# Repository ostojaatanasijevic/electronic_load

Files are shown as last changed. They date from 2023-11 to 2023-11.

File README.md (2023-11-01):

# electronic_load
Open hardware modular electronic load

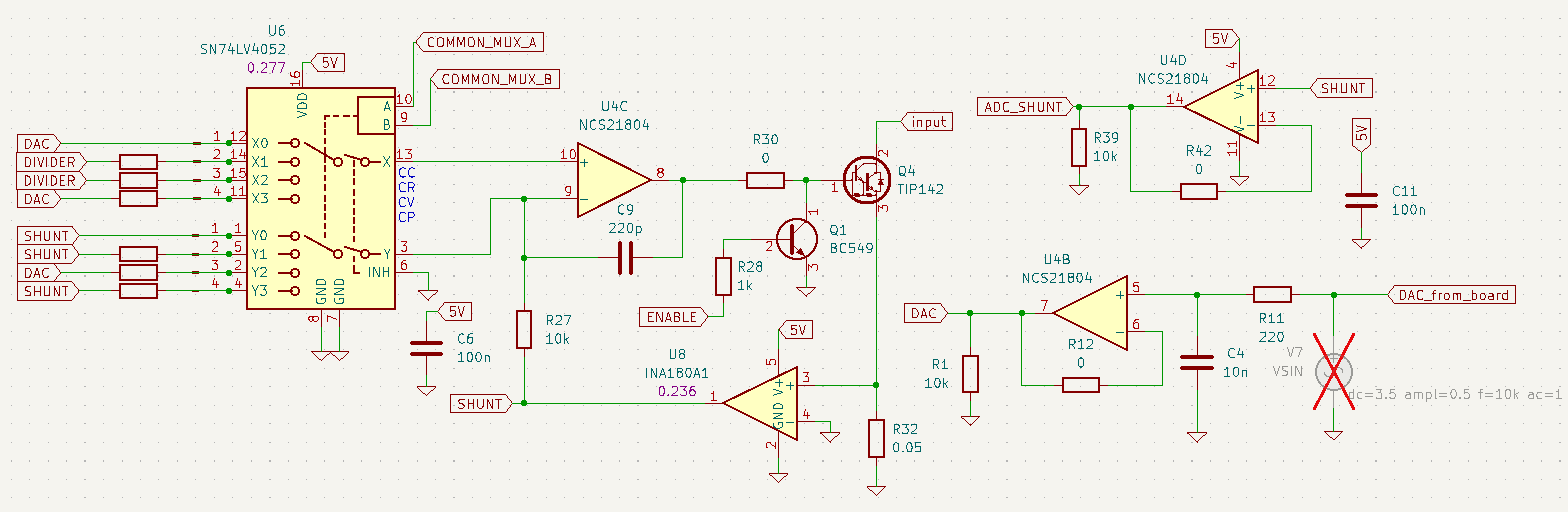
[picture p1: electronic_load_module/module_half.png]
Modular nature of the instrument is based around dual darlington module boards, each containing 2 of the schematic blocks shown below 
This module is designed for 8A and 2V - 60V operation with a maximum disipation of around 100W.

Control signals are generated by the general purpose front panel module. Using a panel with 12 bit ADC and DAC yealds 1 mA control
and sense accuracy.

Vcesat shortcoming of the darlington modules can be overcome by an addition of a singular mosfet based module. 

Additinal modules like the analog mixer circuit for fast CR and CP modes are in the works.

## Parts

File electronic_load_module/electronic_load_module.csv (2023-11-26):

Source: | /home/ostoja/Elektronika/Projekti/electronic_load/electronic_load_module/electronic_load_module.kicad_sch
Date: | Sun Nov 26 00:37:47 2023
Tool: | Eeschema 7.0.9
Generator: | /usr/share/kicad/plugins/extract_price.py
Component Count: | 43
Collated Components:
Item | Qty | Reference(s) | Value | LibPart | Footprint | Datasheet | DNP | Price | Sim.Device | Sim.Enable | Sim.Library | Sim.Name | Sim.Params | Sim.Pins | Sim.Type
1 | 2
2 | 5
3 | 2
4 | 2 | 0.184
5 | 2
6 | 2 | 0.04
7 | 2 | 0.02
8 | 2 | 0.994
9 | 2 | 2.52
10 | 6
11 | 2
12 | 2
13 | 2
14 | 2
15 | 2 | 0.704
16 | 1 | 1.91
17 | 1 | 0.412
18 | 2 | 0.554
19 | 2 | 0.472

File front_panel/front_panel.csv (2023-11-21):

Source: | /home/ostoja/Elektronika/Projekti/elektronsko_opterecenje/front_panel/front_panel.kicad_sch
Date: | Tue Nov 21 00:17:31 2023
Tool: | Eeschema 7.0.8
Generator: | /usr/share/kicad/plugins/extract_price.py
Component Count: | 39
Collated Components:
Item | Qty | Reference(s) | Value | LibPart | Footprint | Datasheet | DNP | Price | Sim.Device | Sim.Library | Sim.Name | Sim.Pins | Type
1 | 2
2 | 1 | 0.015
3 | 2 | 0.02
4 | 1 | 4.0
5 | 14 | 0.14
6 | 1 | 0.02
7 | 2 | 0.38
8 | 2
9 | 2
10 | 1 | 0.35
11 | 2 | 3.82
12 | 1 | 0.358
13 | 2 | 1.6
14 | 1
15 | 1
16 | 1 | 4.0
17 | 2 | 0.818
18 | 1 | 1.11

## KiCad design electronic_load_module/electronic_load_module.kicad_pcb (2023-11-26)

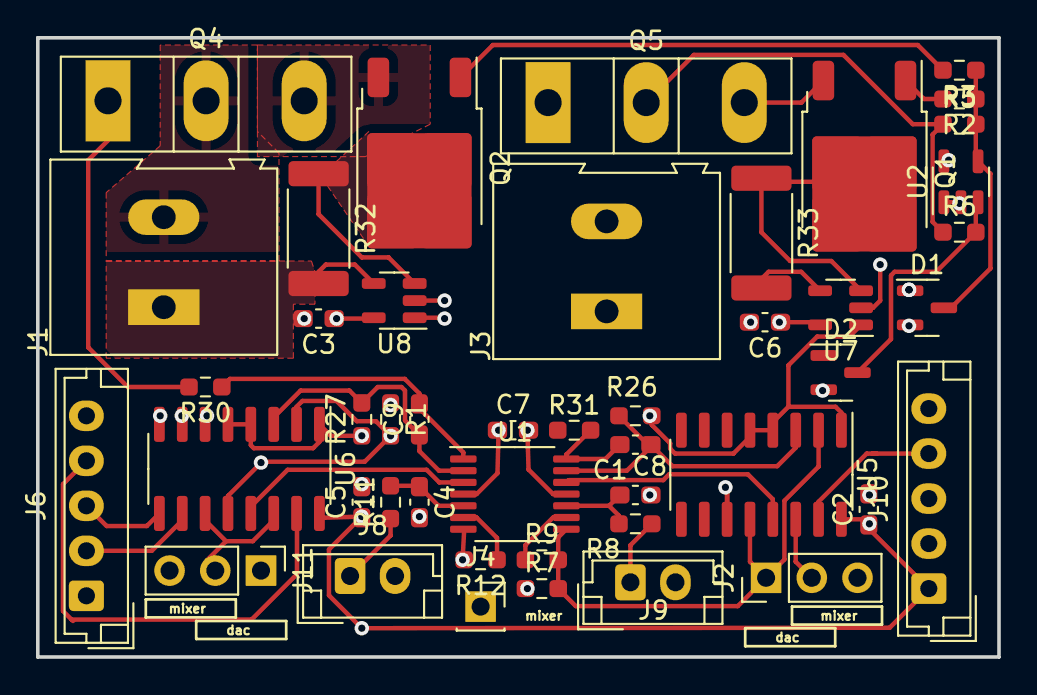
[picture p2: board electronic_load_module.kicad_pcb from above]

Board: 4 copper layers, 53.4 x 34.4 mm, 46 parts (0 on the bottom side), 35 nets.

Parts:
C1, C4: 1n; C_0603_1608Metric_Pad1.08x0.95mm_HandSolder
C2, C3, C5, C6, C7: 100n; C_0603_1608Metric_Pad1.08x0.95mm_HandSolder
C8, C9: 220p; C_0603_1608Metric_Pad1.08x0.95mm_HandSolder
D1, D2: BAT54S; SOT-23
J1, J3: Screw_Terminal_01x02; TerminalBlock_Altech_AK300-2_P5.00mm
J2, J11: Conn_01x03_Pin; PinHeader_1x03_P2.54mm_Vertical
J4: Conn_01x01_Socket; PinSocket_1x01_P2.54mm_Vertical
J6, J10: Conn_01x05_Pin; JST_EH_B5B-EH-A_1x05_P2.50mm_Vertical
J8, J9: Conn_01x02_Socket; JST_EH_B2B-EH-A_1x02_P2.50mm_Vertical
Q1, Q2: DMT10H025SK3-13; TO-252-2
Q4, Q5: TIP142; TO-247-3_Vertical
R1, R5, R6, R7, R26, R27: 10k; R_0603_1608Metric_Pad0.98x0.95mm_HandSolder
R2, R3: 100; R_0603_1608Metric_Pad0.98x0.95mm_HandSolder
R8, R11: 220; R_0603_1608Metric_Pad0.98x0.95mm_HandSolder
R9, R12: 0; R_0603_1608Metric_Pad0.98x0.95mm_HandSolder
R30, R31: 3.3k; R_0603_1608Metric_Pad0.98x0.95mm_HandSolder
R32, R33: 0.05; R_2512_6332Metric_Pad1.40x3.35mm_HandSolder
U1: NCS21804; TSSOP-14_4.4x5mm_P0.65mm
U2: MCP6541; SOT-23-5
U5, U6: SN74LV4052; SOIC-16_3.9x9.9mm_P1.27mm
U7, U8: INA180A1; SOT-23-5

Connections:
0: C1.2, C2.2, C3.2, C4.2, C5.2, C6.2, C7.2, D1.1 (A), D2.1 (A), D2.2 (K), J1.1, J3.1, J6.5, J10.5, R1.1, R7.1, R32.2, R33.2, U1.11 (V-), U2.1 (-), U2.2 (V-), U5.6 (INH), U5.7 (GND), U5.8 (GND), U6.6 (INH), U6.7 (GND), U6.8 (GND), U7.2 (GND), U7.4 (-), U8.2 (GND), U8.4 (-)
5V: C2.1, C3.1, C5.1, C6.1, C7.1, D1.2 (K), J6.1, J10.1, U1.4 (V+), U2.5 (V+), U5.16 (VDD), U6.16 (VDD), U7.5 (V+), U8.5 (V+)
COMMON_MUX_A: J6.2, J10.2, U5.10 (A), U6.10 (A)
COMMON_MUX_B: J6.3, J10.3, U5.9 (B), U6.9 (B)
DAC: J11.1, R1.2, R12.2, U1.7, U6.2 (Y2), U6.12 (X0)
DAC_2: J2.1, R7.2, R9.2, U1.8, U5.2 (Y2), U5.12 (X0)
DAC_from_board: J8.1, R11.1
DAC_from_board_2: J9.1, R8.1
DIVIDER: J6.4, J10.4, U5.15 (X2), U6.15 (X2)
MIXER: J2.3, J4.1, J11.3
unnamed: C8.2, R31.1, U1.14
unnamed: C9.2, R30.1, U1.1
unnamed: D2.3 (COM), R6.2, U2.3 (+)
unnamed: J2.2, U5.11 (X3), U5.14 (X1)
unnamed: J11.2, U6.11 (X3), U6.14 (X1)
unnamed: Q1.2 (D), R33.1, U7.3 (+)
unnamed: Q1.1 (G), R2.2
unnamed: Q1.3 (S), Q5.3 (E)
unnamed: Q2.2 (D), R32.1, U8.3 (+)
unnamed: Q2.1 (G), R3.2
unnamed: Q2.3 (S), Q4.3 (E)
unnamed: Q4.1 (B), R30.2
unnamed: Q5.1 (B), R31.2
unnamed: U1.3 (+), U6.13 (X)
unnamed: C9.1, R27.2, U1.2 (-), U6.3 (Y)
unnamed: C4.1, R11.2, U1.5 (+)
unnamed: R12.1, U1.6 (-)
unnamed: C1.1, R8.2, U1.10 (+)
unnamed: R9.1, U1.9 (-)
unnamed: U1.12 (+), U5.13 (X)
unnamed: C8.1, R26.2, U1.13 (-), U5.3 (Y)
P_GATE: D1.3 (COM), R2.1, R3.1, R5.2, U2.4
SHUNT: J8.2, R27.1, U6.1 (Y0), U6.4 (Y3), U6.5 (Y1), U8.1
SHUNT_2: J9.2, R26.1, U5.1 (Y0), U5.4 (Y3), U5.5 (Y1), U7.1
input: J1.2, J3.2, Q4.2 (C), Q5.2 (C), R5.1, R6.1

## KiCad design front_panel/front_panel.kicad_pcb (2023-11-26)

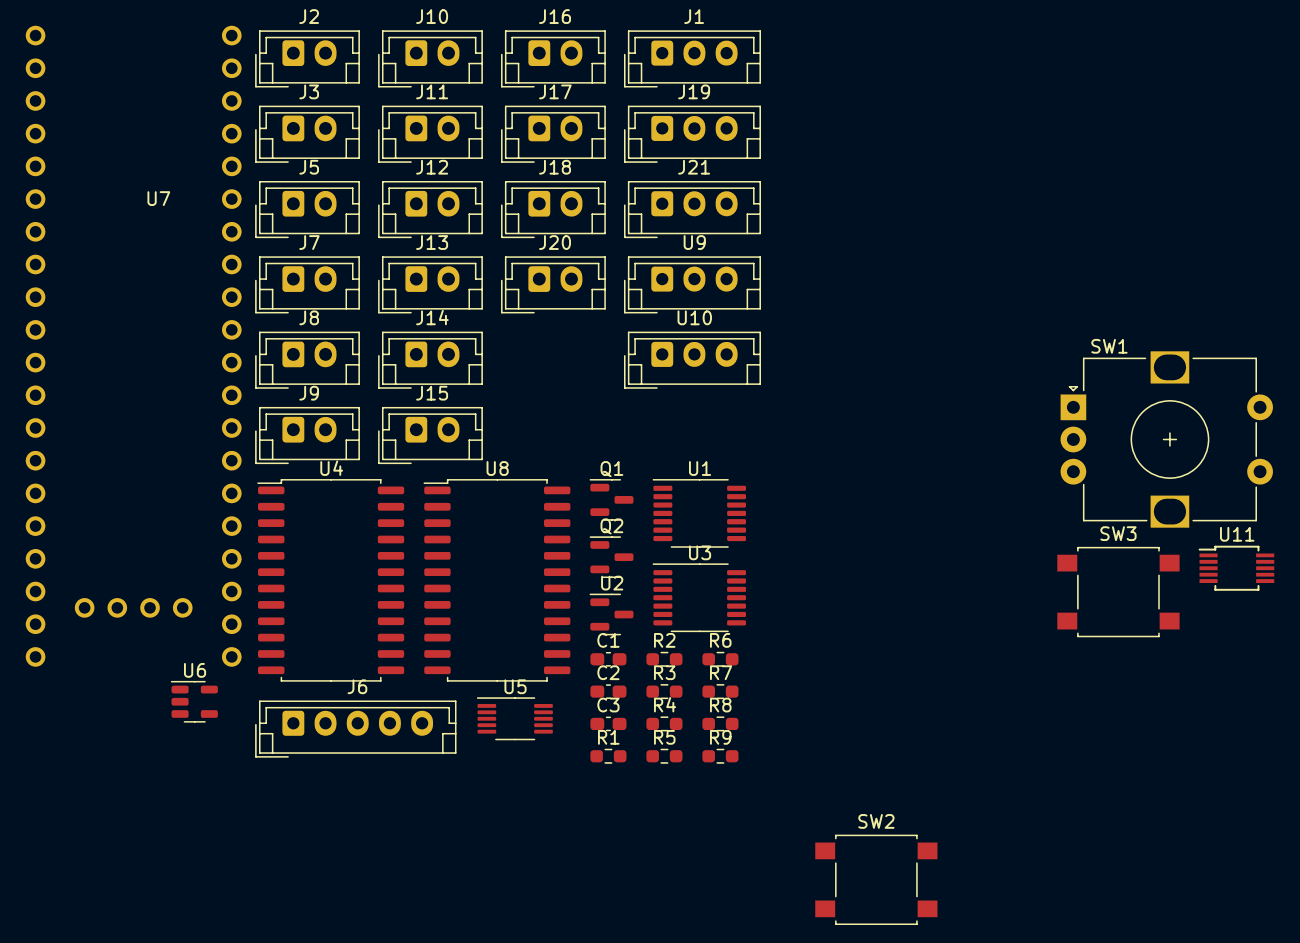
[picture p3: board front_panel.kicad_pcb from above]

Board: 2 copper layers, 48 parts (0 on the bottom side), 68 nets, no tracks yet.

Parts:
C1, C2: 1u; C_0603_1608Metric_Pad1.08x0.95mm_HandSolder
C3: 100n; C_0603_1608Metric_Pad1.08x0.95mm_HandSolder
J1: Conn_01x03_Socket; JST_EH_B3B-EH-A_1x03_P2.50mm_Vertical
J2, J3, J5, J7, J8, J9, J10, J11, J12, J13, J14, J15, J16, J17, J18, J20: Conn_01x02_Socket; JST_EH_B2B-EH-A_1x02_P2.50mm_Vertical
J6: Conn_01x05_Pin; JST_EH_B5B-EH-A_1x05_P2.50mm_Vertical
J19, J21: Conn_01x03_Pin; JST_EH_B3B-EH-A_1x03_P2.50mm_Vertical
Q1, Q2: DMN3023L; SOT-23
R1, R2, R9: 1k; R_0603_1608Metric_Pad0.98x0.95mm_HandSolder
R3, R4: 220; R_0603_1608Metric_Pad0.98x0.95mm_HandSolder
R5: 90k; R_0603_1608Metric_Pad0.98x0.95mm_HandSolder
R6: 3.3k; R_0603_1608Metric_Pad0.98x0.95mm_HandSolder
R7: 6.6k; R_0603_1608Metric_Pad0.98x0.95mm_HandSolder
R8: 100; R_0603_1608Metric_Pad0.98x0.95mm_HandSolder
SW1: RotaryEncoder_Switch; RotaryEncoder_Alps_EC12E-Switch_Vertical_H20mm
SW2, SW3: SW_MEC_5G; SW_SPST_B3S-1000
U1, U3: NCS21804; TSSOP-14_4.4x5mm_P0.65mm
U2: LM4040DBZ-4.1; SOT-23
U4, U8: CD74HC4067M; SOIC-24W_7.5x15.4mm_P1.27mm
U5: DAC60501; VSSOP-10_3x3mm_P0.5mm
U6: MIC5504-1.8YM5; SOT-23-5
U7: BP; blue_pill
U9, U10: MCP9700x-ETT; JST_EH_B3B-EH-A_1x03_P2.50mm_Vertical
U11: MCP33141D-05; MSOP-10_3x3mm_P0.5mm

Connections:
0: C1.2, C2.2, C3.2, J1.3, J6.5, J19.3, Q1.2 (S), Q2.2 (S), R8.2, R9.1, U2.2 (A), U3.11 (V-), U4.12 (GND), U4.15 (~E), U5.4 (Vss), U5.5 (SPI2C), U6.2 (GND), U7.G (GND), U8.12 (GND), U8.15 (~E), U9.3 (GND), U10.3 (GND), U11.4 (IN-), U11.5 (GND)
1.8V: C2.1, U6.5 (VOUT), U11.2 (AVdd)
3.3V: C1.1, U6.1 (VIN), U6.3 (EN), U11.9 (SDI), U11.10 (DVio)
4V_ref: R1.2, U2.1 (K), U5.10 (Vref), U11.1 (Vref)
5V: C3.1, J1.2, J6.1, R1.1, R2.1, SW2.1 (A), SW2.2 (A), SW3.1 (A), SW3.2 (A), U3.4 (V+), U4.24 (VCC), U5.1 (Vdd), U7.5V, U8.24 (VCC), U9.1 (V_{DD}), U10.1 (V_{DD})
12V: J1.1, J2.1, J3.1
A0: J5.2, U4.9 (I0)
A1: J7.2, U4.8 (I1)
A2: J8.2, U4.7 (I2)
A3: J12.2, U4.6 (I3)
A4: J9.2, U4.5 (I4)
A5: J10.2, U4.4 (I5)
A6: J11.2, U4.3 (I6)
A7: J20.2, U4.2 (I7)
A8: J13.2, U4.23 (I8)
A9: J14.2, U4.22 (I9)
A10: J15.2, U4.21 (I10)
A11: J16.2, U4.20 (I11)
A12: J17.2, U4.19 (I12)
A13: J18.2, U4.18 (I13)
B0: U7.PA8, U7.PA9, U7.PA10, U7.PA15, U7.PB0, U7.PB1, U7.PB10, U7.PB12
CNVST: U7.PA7, U11.6 (CNVST)
D0: J5.1, U8.9 (I0)
D1: J7.1, U8.8 (I1)
D2: J8.1, U8.7 (I2)
D3: J12.1, U8.6 (I3)
D4: J9.1, U8.5 (I4)
D5: J10.1, U8.4 (I5)
D6: J11.1, U8.3 (I6)
D7: J20.1, U8.2 (I7)
D8: J13.1, U8.23 (I8)
D9: J14.1, U8.22 (I9)
D10: J15.1, U8.21 (I10)
D11: J16.1, U8.20 (I11)
D12: J17.1, U8.19 (I12)
D13: J18.1, U8.18 (I13)
DIVIDER: J6.4, R9.2, U3.8, U3.9 (-), U4.16 (I15)
DIVIDER_R: R6.2, R7.1, U3.10 (+)
FC1: R3.1, U7.PB3
FC2: R4.1, U7.PB4
INPUT0: U4.10 (S0), U7.PA1
INPUT1: U4.11 (S1), U7.PA2
INPUT2: U4.14 (S2), U7.PA3
INPUT3: U4.13 (S3), U7.PA4
unnamed: J2.2, Q1.3 (D)
unnamed: J3.2, Q2.3 (D)
unnamed: Q1.1 (G), R3.2
unnamed: Q2.1 (G), R4.2
unnamed: R2.2, SW1.C, SW1.S1
unnamed: SW1.A, U7.PB8
unnamed: SW1.B, U7.PB9
unnamed: SW1.S2, U7.PB7
unnamed: U1.3 (+), U4.1 (COM)
unnamed: U3.12 (+), U5.2 (VOUT)
unnamed: U3.13 (-), U3.14, U8.1 (COM)
unnamed: U1.1, U1.2 (-), U11.3 (IN+)
OUTPUT0: U7.PC13, U8.10 (S0)
OUTPUT1: U7.PC14, U8.11 (S1)
OUTPUT2: U7.PC15, U8.14 (S2)
OUTPUT3: U7.PA0, U8.13 (S3)
SPI1_CLK: U5.6 (SCLK), U7.PA5, U7.PB13, U11.8 (SCLK)
SPI1_MISO: U7.PA6, U11.7 (SDO)
SPI1_MOSI: U5.7 (SDA), U7.PB15
T1: U7.PB6, U9.2 (V_{OUT})
T2: U7.PB5, U10.2 (V_{OUT})
input_10: J21.1, R5.2, R6.1
input_1000: J21.2, R7.2, R8.1
input_sense: J19.1, R5.1

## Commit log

2023-11-01 Image added
    [electronic_load_module.kicad_sch]
2023-11-21 IDeo ok
    [electronic_load_module.kicad_pcb, electronic_load_module.kicad_sch]
2023-11-26 Konačno PCB za BJT modul je počeo.
    [electronic_load_module.csv, electronic_load_module.kicad_pcb, electronic_load_module.kicad_sch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]
